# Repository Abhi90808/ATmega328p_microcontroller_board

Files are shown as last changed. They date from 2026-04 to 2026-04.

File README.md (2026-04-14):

# ATmega328P Arduino Nano Clone — Custom MCU PCB Design

> A fully custom Arduino Nano-compatible microcontroller board designed from scratch in KiCad. Implements the ATmega328P with USB-to-serial programming, onboard 5V/3.3V regulation, and a compact 2-layer layout — production-ready and Gerber-verified.

---

## Overview

This project is a **ground-up recreation of the Arduino Nano form factor** using the ATmega328P microcontroller. Rather than using a pre-made module, the entire hardware stack was designed from scratch: oscillator circuit, decoupling strategy, USB-to-serial bridge for bootloader programming, voltage regulation, and pin breakout — all laid out in a compact 2-layer PCB.

This project demonstrates the ability to design real microcontroller hardware — the kind of work needed for custom embedded products where off-the-shelf dev boards aren't suitable.

---

## Specifications

| Parameter | Value |
|---|---|
| MCU | ATmega328P-AU (TQFP-32) |
| Clock | 16 MHz external crystal |
| USB Interface | CH340G USB-to-Serial bridge |
| Supply Voltage | 5V via USB |
| Onboard Regulation | AMS1117-3.3 (3.3V LDO) |
| I/O Voltage | 5V logic |
| GPIO Pins | 22 (14 digital, 8 analog) |
| Programming | USB (bootloader) / ICSP header |
| PCB Layers | 2 |
| Board Status | Design complete, DRC passed |
| Tool | KiCad |

---

## Design Highlights

### Full ATmega328P Bring-Up Circuit
Includes all essential support circuitry: 16 MHz crystal with load capacitors, AVCC filtering with a ferrite bead and bulk capacitor, 100nF decoupling caps on all VCC/GND pins, and a proper reset circuit with pull-up resistor and filter capacitor.

### USB-to-Serial Programming
The CH340G bridge handles USB communication and auto-reset for bootloader programming, matching the Arduino Nano behaviour exactly. DTR line connected through a 100nF capacitor to the MCU reset pin for reliable auto-reset during upload.

### Onboard 3.3V Regulation
AMS1117-3.3 LDO provides a clean 3.3V rail for sensors and peripherals that require it, with input and output decoupling capacitors for stability.

### Compact 2-Layer Layout
All components fit within a Nano-compatible footprint on a 2-layer board. Power and ground planes on bottom layer, signals routed cleanly on top. SMD components used throughout for compact placement.

### DRC Passed
Full design rule check with zero errors. Trace widths verified for current capacity, clearances verified for standard PCB fab tolerances.

---

## Repository Structure

```
project2-atmega328p-nano/
├── schematic/
│   └── atmega328p_nano.kicad_sch
├── pcb/
│   └── atmega328p_nano.kicad_pcb
├── gerbers/
│   ├── atmega328p_nano.GTL
│   ├── atmega328p_nano.GBL
│   ├── atmega328p_nano.GTO
│   ├── atmega328p_nano.GTS
│   ├── atmega328p_nano.GBS
│   └── atmega328p_nano.DRL
├── bom/
│   └── bom.csv
└── README.md
```

---

## Bill of Materials (Key Components)

| Ref | Component | Part Number | Package |
|---|---|---|---|
| U1 | Microcontroller | ATmega328P-AU | TQFP-32 |
| U2 | USB-Serial Bridge | CH340G | SOP-16 |
| U3 | 3.3V LDO Regulator  | AMS1117-3.3 | SOT-223 |
| Y1 | Crystal Oscillator  | 16 MHz | HC-49S |
| C1, C2 | Crystal Load Caps | 22pF | 0402 |
| C3–C10 | Decoupling Caps | 100nF | 0402 |
| R1 | Reset Pull-up | 10kΩ | 0402 |
| J1 | USB Connector | Mini-USB Female | SMD |
| J2, J3 | Pin Headers | 2.54mm, 15-pin | Through-hole |
| J4 | ICSP Header | 2×3, 2.54mm | Through-hole |

---

## Schematic Sections

1. **Power input & regulation** — USB 5V in → AMS1117-3.3 → 3.3V rail
2. **USB-to-Serial** — CH340G with crystal, decoupling, and DTR auto-reset
3. **ATmega328P core** — MCU with crystal, decoupling, AVCC filter, reset
4. **I/O breakout** — all GPIO, analog, and power pins exposed on 2.54mm headers
5. **ICSP header** — for bootloader burning and direct ISP programming

---

## Skills Demonstrated

- ATmega328P hardware bring-up and support circuit design
- USB-to-serial bridge integration (CH340G)
- LDO regulator selection and decoupling strategy
- SMD component placement and 2-layer PCB routing
- ICSP and bootloader programming interface design
- KiCad DRC and Gerber export

---

## Project Status

| Stage | Status |
|---|---|
| Schematic | ✅ Complete  |
| PCB Layout | ✅ Complete  |
| DRC | ✅ Passed |
| Gerbers Exported | ✅ Ready |
| Fabricated | ⬜ Not yet |
| Tested | ⬜ Not yet |

---

## About the Designer

Self-taught PCB designer specializing in KiCad — IoT, embedded systems, and industrial control boards.
Available for freelance PCB design work: schematic capture, layout, DRC review, and Gerber preparation.

🔗 GitHub: [Abhi90808]
📧 [kvabhishek908@gmail.com]

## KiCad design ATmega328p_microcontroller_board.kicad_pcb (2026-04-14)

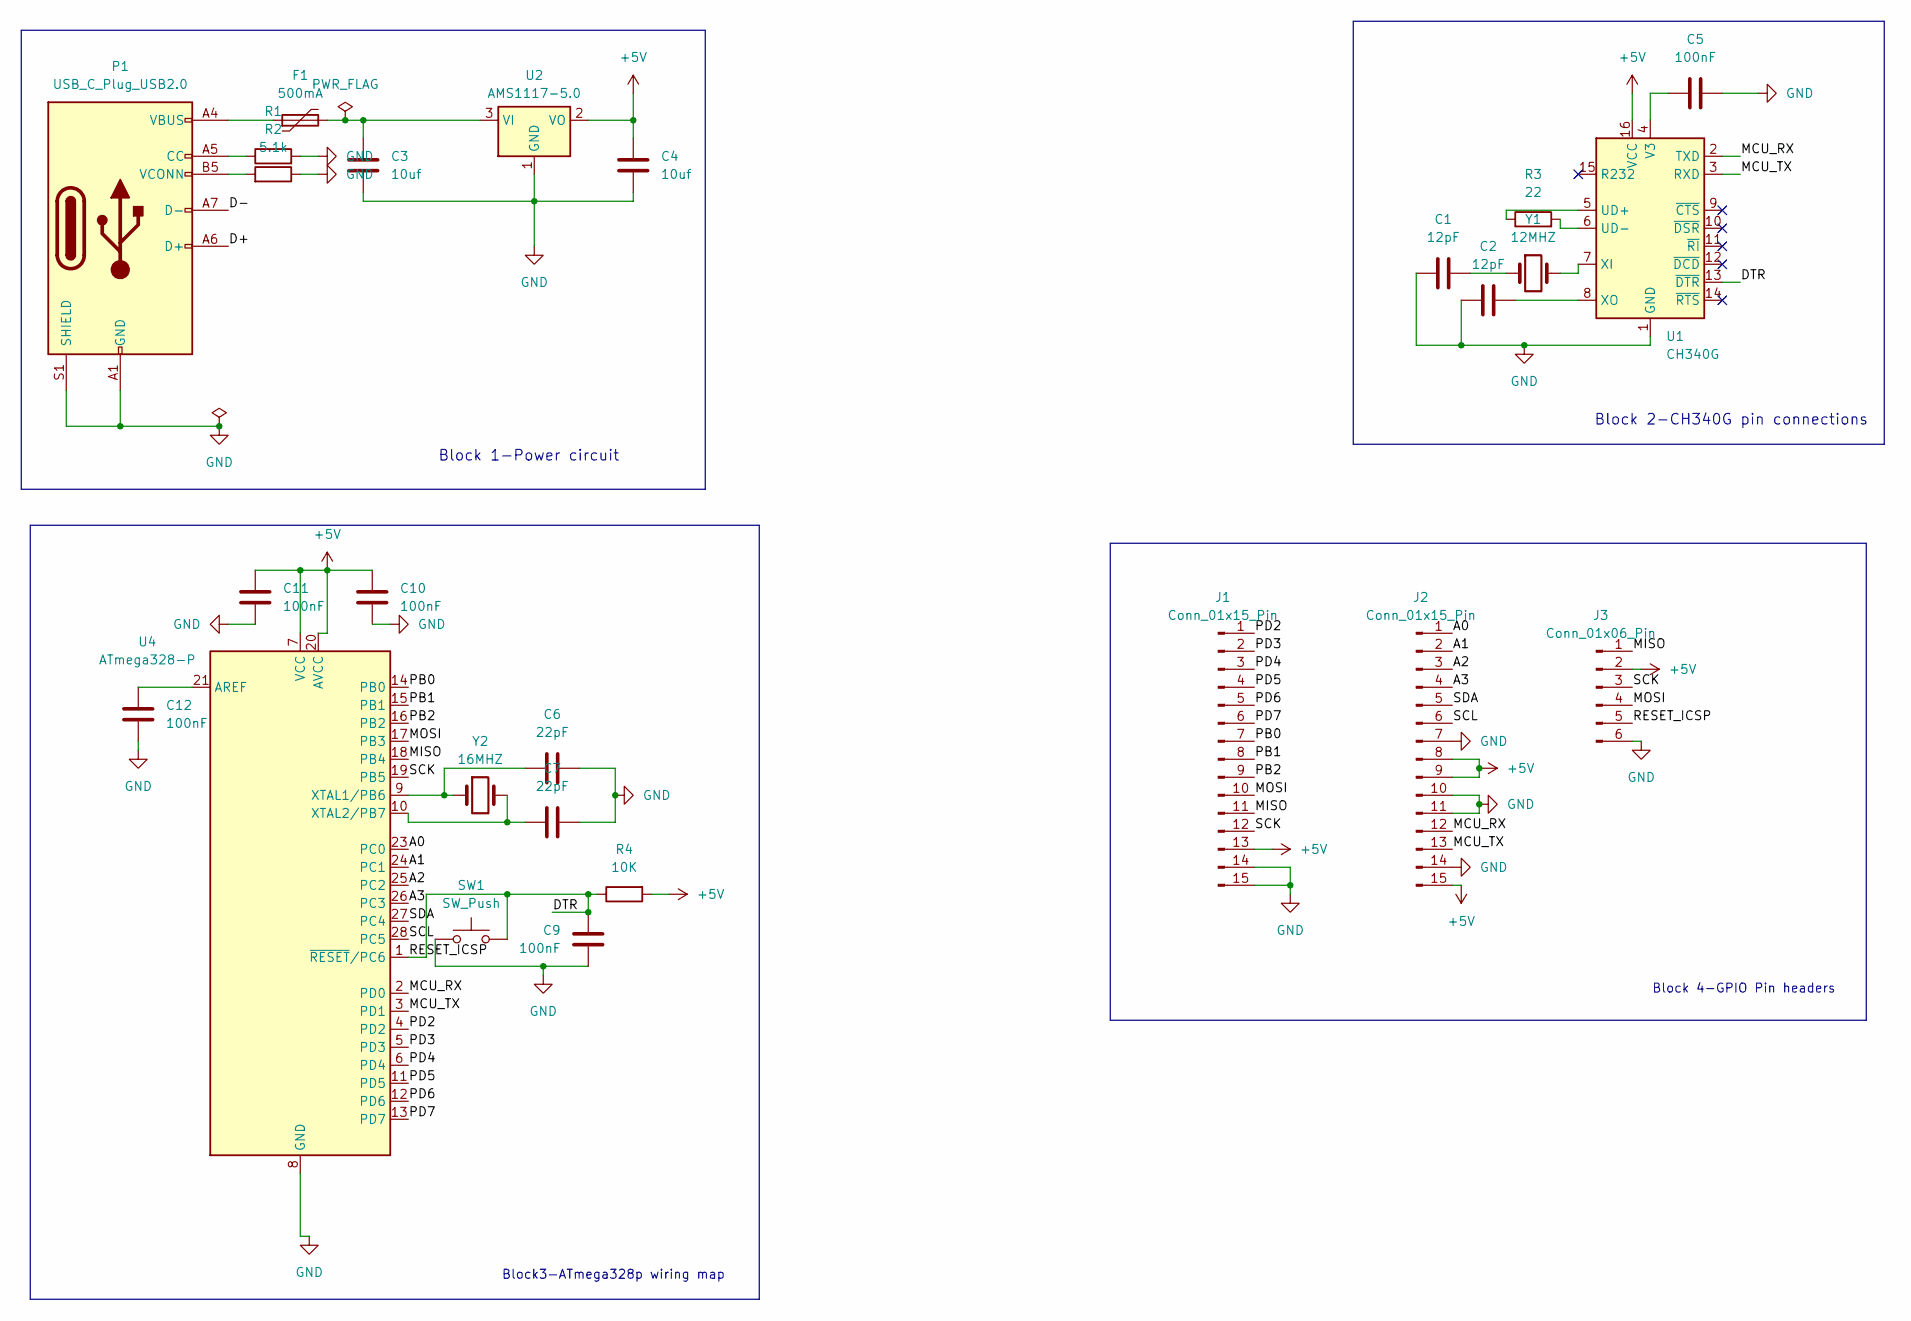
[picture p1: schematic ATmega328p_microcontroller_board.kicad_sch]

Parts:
C1, C2: 12pF; C_0402_1005Metric
C3, C4: 10uf; C_0805_2012Metric
C5, C9, C10, C11, C12: 100nF; C_0402_1005Metric
C6, C7: 22pF; C_0402_1005Metric
F1: 500mA; Fuse_0805_2012Metric
J1, J2: Conn_01x15_Pin; PinHeader_1x15_P2.54mm_Vertical
J3: Conn_01x06_Pin; PinHeader_2x03_P2.54mm_Vertical
P1: USB_C_Plug_USB2.0; USB_C_Receptacle_HRO_TYPE-C-31-M-12
R1: 5.1K; R_0402_1005Metric
R2: 5.1k; R_0402_1005Metric
R3: 22; R_0402_1005Metric
R4: 10K; R_0402_1005Metric
SW1: SW_Push; SW_SPST_B3U-1000P
U1: CH340G; SOIC-16_3.9x9.9mm_P1.27mm
U2: AMS1117-5.0; SOT-223-3_TabPin2
U4: ATmega328-P; TQFP-32_7x7mm_P0.8mm
Y1: 12MHZ; Crystal_SMD_3225-4Pin_3.2x2.5mm
Y2: 16MHZ; Crystal_SMD_3225-4Pin_3.2x2.5mm

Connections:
+5V: C4.1, C10.2, C11.2, J1.13, J2.8, J2.9, J2.15, J3.2, R4.2, U1.16 (VCC), U2.2 (VO), U4.7 (VCC), U4.20 (AVCC)
/A0: J2.1, U4.23 (PC0)
/A1: J2.2, U4.24 (PC1)
/A2: J2.3, U4.25 (PC2)
/A3: J2.4, U4.26 (PC3)
/D+: P1.A6 (D+)
/D-: P1.A7 (D-)
/DTR: C9.1, J3.5, R4.1, SW1.1, U1.13 (~DTR), U4.1 (~RESET/PC6)
/MCU_RX: J2.12, U1.2 (TXD), U4.2 (PD0)
/MCU_TX: J2.13, U1.3 (RXD), U4.3 (PD1)
/MISO: J1.11, J3.1, U4.18 (PB4)
/MOSI: J1.10, J3.4, U4.17 (PB3)
/PB0: J1.7, U4.14 (PB0)
/PB1: J1.8, U4.15 (PB1)
/PB2: J1.9, U4.16 (PB2)
/PD2: J1.1, U4.4 (PD2)
/PD3: J1.2, U4.5 (PD3)
/PD4: J1.3, U4.6 (PD4)
/PD5: J1.4, U4.11 (PD5)
/PD6: J1.5, U4.12 (PD6)
/PD7: J1.6, U4.13 (PD7)
/SCK: J1.12, J3.3, U4.19 (PB5)
/SCL: J2.6, U4.28 (PC5)
/SDA: J2.5, U4.27 (PC4)
GND: C1.2, C2.1, C3.2, C4.2, C5.2, C6.2, C7.2, C9.2, C10.1, C11.1, C12.1, J1.14, J1.15, J2.7, J2.10, J2.11, J2.14, J3.6, P1.A1 (GND), P1.A12 (GND), P1.B1 (GND), P1.B12 (GND), P1.S1 (SHIELD), R1.2, R2.1, SW1.2, U1.1 (GND), U2.1 (GND), U4.8 (GND), U4.22 (GND)
unnamed: C1.1, Y1.1
unnamed: F1.1, P1.A4 (VBUS), P1.A9 (VBUS), P1.B4 (VBUS), P1.B9 (VBUS)
unnamed: P1.A5 (CC), R1.1
unnamed: P1.B5 (VCONN), R2.2
unnamed: R3.1, U1.5 (UD+)
unnamed: R3.2, U1.6 (UD-)
unnamed: C5.1, U1.4 (V3)
unnamed: U1.7 (XI), Y1.2
unnamed: C2.2, U1.8 (XO)
unnamed: C3.1, F1.2, U2.3 (VI)
unnamed: C12.2, U4.21 (AREF)
unnamed: C6.1, U4.9 (XTAL1/PB6), Y2.1
unnamed: C7.1, U4.10 (XTAL2/PB7), Y2.2

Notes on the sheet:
Block 4-GPIO Pin headers
Block 1-Power circuit
Block 2-CH340G pin connections
Block3-ATmega328p wiring map

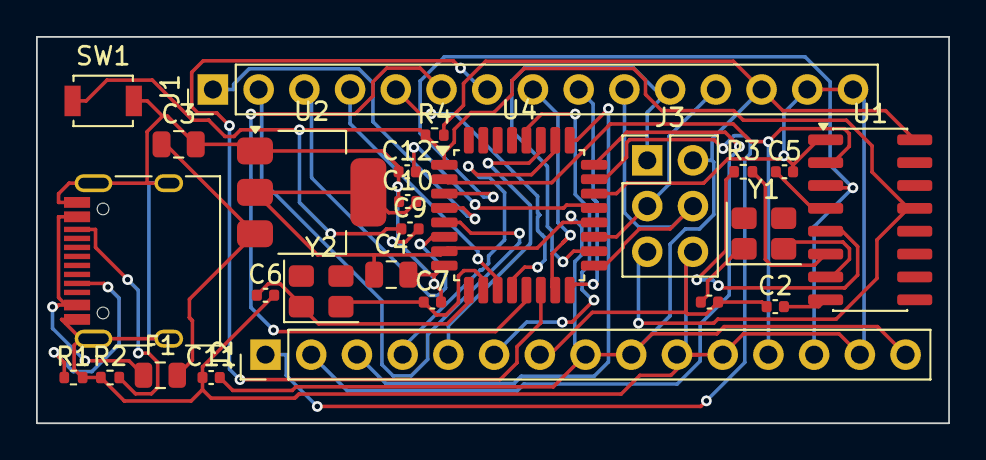
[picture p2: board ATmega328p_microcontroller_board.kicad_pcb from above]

Board: 2 copper layers, 50.7 x 21.5 mm, 26 parts (0 on the bottom side), 36 nets.
